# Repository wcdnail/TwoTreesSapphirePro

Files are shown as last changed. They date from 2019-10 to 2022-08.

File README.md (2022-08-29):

# Marlin для TwoTrees Sapphire Pro
## Версия Марлин - 2.1.x, обновлена 26.08.2022

### Внимание!
 - MarlinSP - теперь подмодуль git
 - MKS Robin Nano - STM32F103VET6
 - Баг №1 - произвольное движение каретки при печати - воспроизводится на модерновой гуйне TFT_LVGL_UI
 - ~Драйвера Z & E заменены на 2208~
 - ~Настроен сенсор автоуровня емкостный~ - в прошивке запрещен
 - Настройки сохраняются в SPI Flash (см. Marlin2/src/HAL/HAL_STM32F1/persistent_store_spi_flash.cpp), спасибо [[@sobieh](https://github.com/sobieh)]
 - С графикой помог Korbinian Heel [[@inib](https://github.com/inib)] https://github.com/inib/Marlin/tree/2.0.X-SapphirePro-3.5TFT https://escope.de/posts/sapphire-pro-marlin/ - это уже в актуальной версии Марлин

### Собирать лучше всего с помощью Visual Studio Code + PlatformIO
[Инструкция по установке Visual Studio Code + PlatformIO](https://docs.platformio.org/en/latest/ide/vscode.html)<br/>

### Прошивка SapphirePro:
* После успешной сборки скопировать файл `MarlinSP\.pio\build\mks_robin_nano\Robin_nano35.bin` на sd карту и переименовать в `Robin_nano.bin`
* Установить sd карту в принтер
* Включить/перезагрузить принтер
* Дождаться обновления

### Графика
[Конвертер графики](http://marlinfw.org/tools/u8glib/converter.html)<br/>
`Marlin2\Marlin\_Bootscreen.h` - `Marlin2\Marlin\Configuration.h:91 #define SHOW_CUSTOM_BOOTSCREEN`<br/>
`Marlin2\Marlin\_Statusscreen.h` - `Marlin2\Marlin\Configuration.h:94 #define CUSTOM_STATUS_SCREEN_IMAGE`<br/>
Так же для модификации смотрите директорию `Pixmaps`<br/>

### Тюнинг PID
Нагреватель: `M303 E0 S200 C8`<br/>
Стол: `M303 E-1 C8 S90`<br/>

### Настройки ПО/слайсеров
  Конфигурация|Значение|Примечание
  ------------|----|------
  Скорость соединения с принтером|250000 бод|
  Размер стола|220х220 мм|Ни каких дополнительных смещений настраивать не надо
  Ретракт|8 мм|В заводских настройках указан 9мм
  Скорость ретракта|35-40 мм/c|

#### Пример настройки Repetier-Host
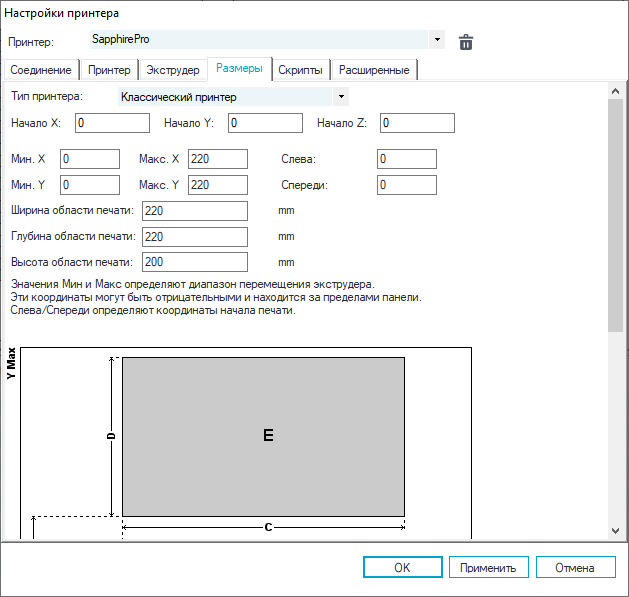
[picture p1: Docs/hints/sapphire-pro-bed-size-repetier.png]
sapphire-pro-bed-size-repetier Размер стола в Repetier-Host


# Железо SapphirePro
 - Матплата - MKS Robin Nano STM32F103VET6
 - Дисплей - MKS TFT35 (3.5" (~9см)) 480*320<br/>

# Стоковые прошивки
`StockFirmwares`

### Скрины
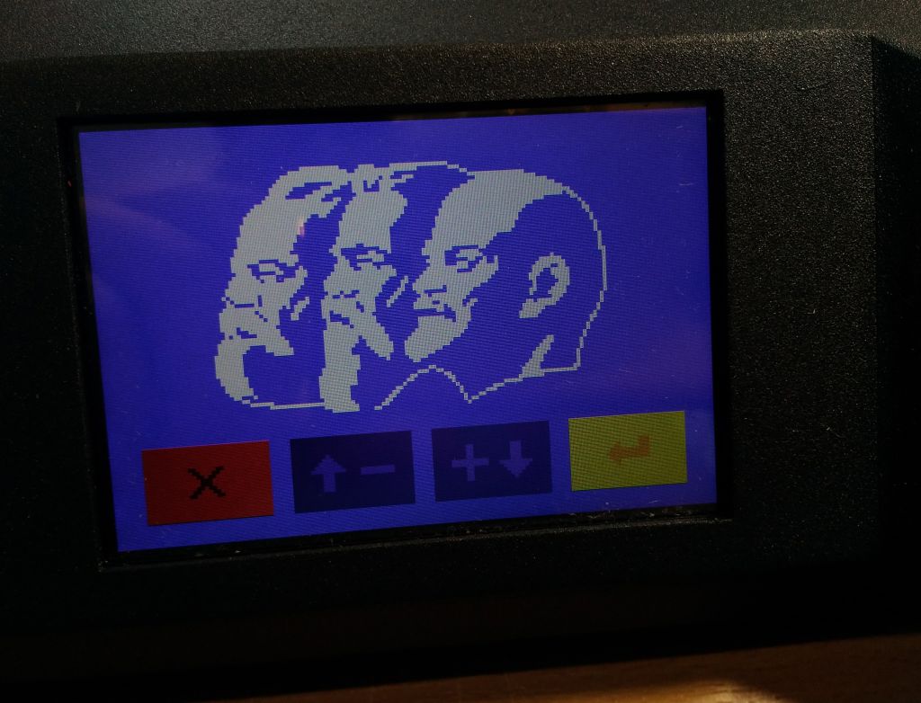
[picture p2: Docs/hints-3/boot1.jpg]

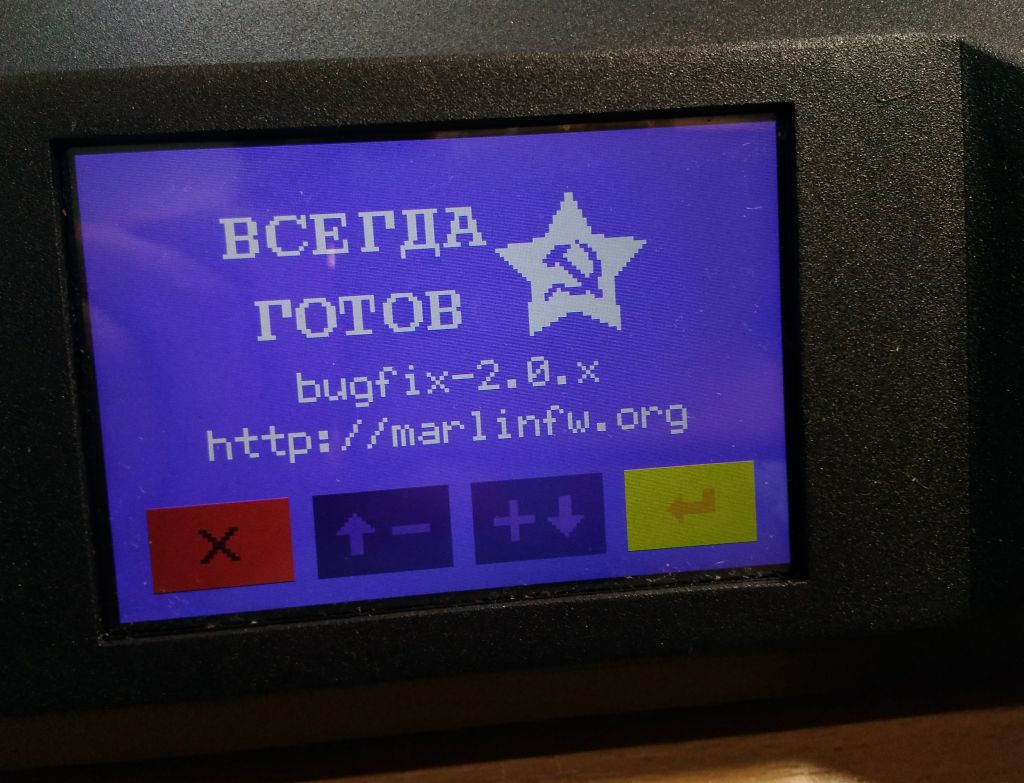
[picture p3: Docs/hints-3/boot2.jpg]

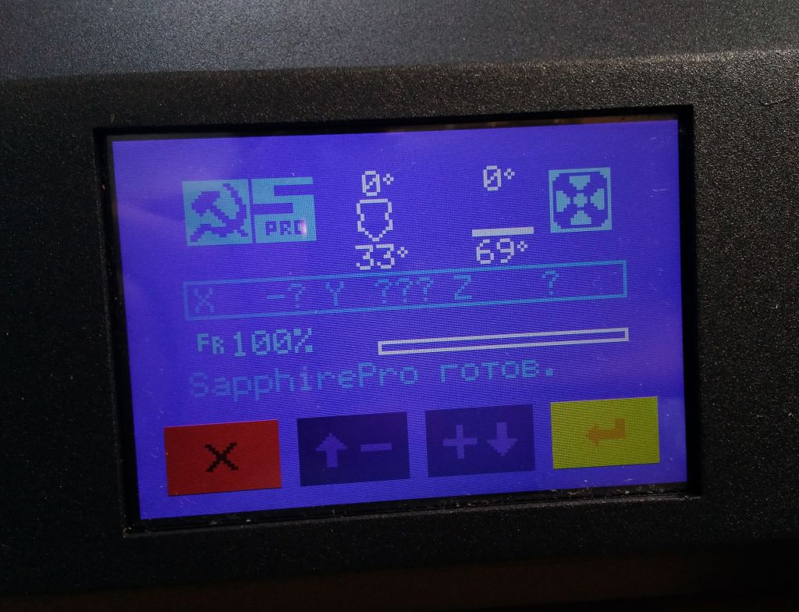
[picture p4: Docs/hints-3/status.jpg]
sapphire-pro-3-marlin-status

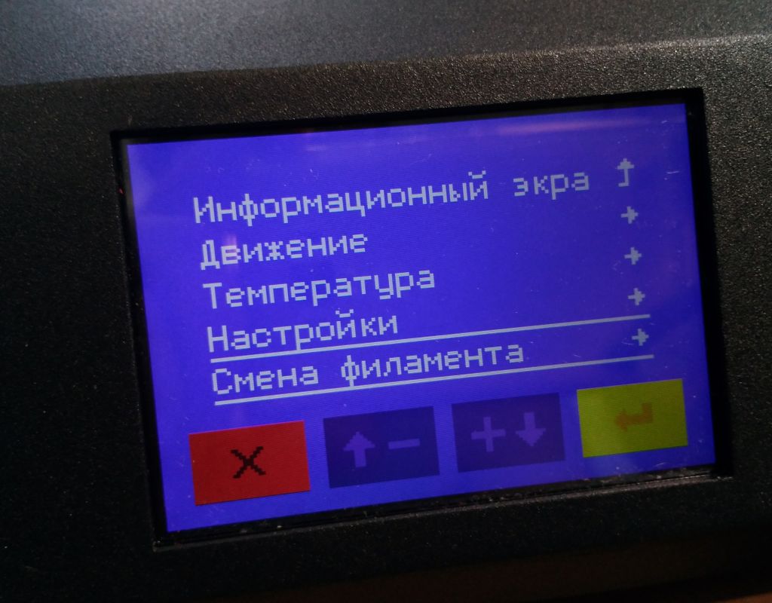
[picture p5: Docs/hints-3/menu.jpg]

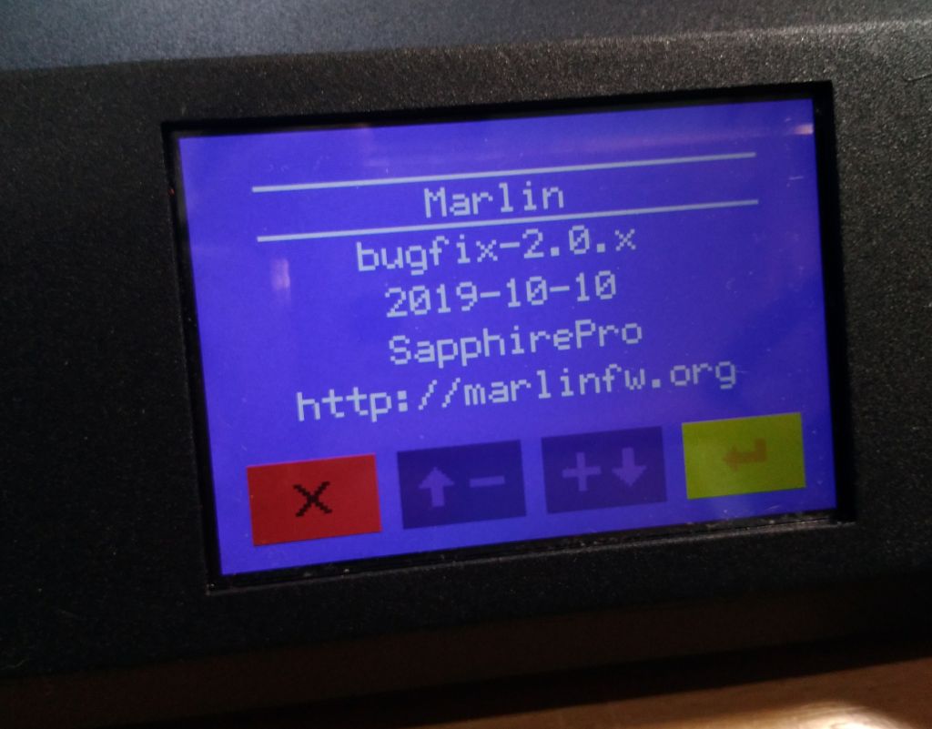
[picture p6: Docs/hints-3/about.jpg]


# Благодарность
## Команде разработчиков марлин
 - Scott Lahteine [[@thinkyhead](https://github.com/thinkyhead)] - USA &nbsp; 
 - Roxanne Neufeld [[@Roxy-3D](https://github.com/Roxy-3D)] - USA
 - Bob Kuhn [[@Bob-the-Kuhn](https://github.com/Bob-the-Kuhn)] - USA
 - Chris Pepper [[@p3p](https://github.com/p3p)] - UK
 - João Brazio [[@jbrazio](https://github.com/jbrazio)] - Portugal
 - Erik van der Zalm [[@ErikZalm](https://github.com/ErikZalm)] - Netherlands &nbsp; 
## С графикой помог
 - Korbinian Heel [[@inib](https://github.com/inib)] https://escope.de/posts/sapphire-pro-marlin/
## EEPROM --> SPI Flash [[@sobieh](https://github.com/sobieh)]
 - https://github.com/inib/Marlin/pull/7

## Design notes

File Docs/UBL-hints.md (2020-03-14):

M190 S75        ; Греем стол
M104 S230       ; Греем хот-енд

M502            ; Сбрасываем текущие настройки
M500            ; Сохраняем текущие настройки
M501            ; Выводим текущие настройки
M851 Z-0.3      ; Установить смещение по Z

G28
G29 P0          ; Zero Mesh Data
G29 T           ; View the Z compensation values.
G29 P1          ; Do automated probing of the bed.
G29 T           ; View the Z compensation values.
G29 S1          ; Save UBL mesh points to EEPROM.
G29 F 30.0      ; Set Fade Height for correction at 30.0 mm.
G29 A           ; Activate the UBL System.
M500            ; Сохраняем текущие настройки. WARNING: UBL will be active at power up, before any `G28`.

G28
G26 B60 H210 F1.75 L0.2 S0.4
 – B температура нагрева стола
 – H температура нагрева экструдера
 – F диаметр филамента
 – L высота слоя 
 - S диаметр сопла

;------------------------------------------
G28
G90                 ; Absolute positioning
G1 Z10 F300         ; Safe Z moving
G1 X110 Y135 F1500  ; Move to centre
M48 P4 V2 E L2      ; Проверить работу датчика уровня
M48 P4 V4 E S1 L3   ; Проверить работу датчика уровня

;------------------------------------------
;--- Setup and initial probing commands ---
;------------------------------------------
M502            ; Reset settings to configuration defaults...
M500            ; ...and Save to EEPROM. Use this on a new install.
M501            ; Read back in the saved EEPROM.  

G28             ; Home XYZ.
G29 P1          ; Do automated probing of the bed.
G29 P2 B T      ; Manual probing of locations USUALLY NOT NEEDED!!!!
G29 P3 T        ; Repeat until all mesh points are filled in.

G29 T           ; View the Z compensation values.
G29 S1          ; Save UBL mesh points to EEPROM.
G29 F 10.0      ; Set Fade Height for correction at 10.0 mm.
G29 A           ; Activate the UBL System.
M500            ; Save current setup. WARNING: UBL will be active at power up, before any `G28`.

;---------------------------------------------
;--- Fine Tuning of the mesh happens below ---
;---------------------------------------------
                
G29 P4 T        ; Move nozzle to 'bad' areas and fine tune the values if needed
                ; Repeat G26 and G29 P4 T  commands as needed.

G29 S1          ; Save UBL mesh values to EEPROM.
M500            ; Resave UBL's state information.

;----------------------------------------------------
;--- Use 3-point probe to transform a stored mesh ---
;----------------------------------------------------
G29 L1          ; Load the mesh stored in slot 1 (from G29 S1)
G29 J           ; No size specified on the J option tells G29 to probe the specified 3 points
                ; and tilt the mesh according to what it finds.

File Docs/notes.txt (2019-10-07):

-- M503 Заводские -------------------------------------------------------------------------------------------------------------------------------------------------------------------------------------------------------------------

08:37:15.982 : echo:  G21    ; Units in mm
08:37:15.985 : echo:Filament settings: Disabled
08:37:15.987 : echo:  M200 D3.00
08:37:15.990 : echo:  M200 T1 D3.00
08:37:15.990 : echo:  M200 D0
08:37:15.993 : echo:Steps per unit:
08:37:15.996 : echo:  M92 X80.30 Y80.30 Z1600.00
08:37:15.999 : echo:  M92 T0 E412.00
08:37:15.999 : M92 T1 E90.00
08:37:16.001 : echo:Maximum feedrates (units/s):
08:37:16.004 : echo:  M203 X200.00 Y200.00 Z4.00
08:37:16.007 : echo:  M203 T0 E70.00
08:37:16.007 : M203 T1 E70.00
08:37:16.012 : echo:Maximum Acceleration (units/s2):
08:37:16.013 : echo:  M201 X1000 Y1000 Z100
08:37:16.015 : echo:  M201 T0 E1000
08:37:16.018 : M201 T1 E1000
08:37:16.024 : echo:Acceleration (units/s2): P<print_accel> R<retract_accel> T<travel_accel>
08:37:16.026 : echo:  M204 P4000.00 R1000.00 T4000.00
08:37:16.038 : echo:Advanced: S<min_feedrate> T<min_travel_feedrate> B<min_segment_time_us> X<max_xy_jerk> Z<max_z_jerk> E<max_e_jerk>
08:37:16.043 : echo:  M205 S0.00 T0.00 B20000 X20.00 Y20.00 Z0.40 E5.00
08:37:16.043 : echo:Home offset:
08:37:16.046 : echo:  M206 X0.00 Y0.00 Z0.00
08:37:16.049 : echo:Hotend offsets:
08:37:16.051 : echo:  M218 T1 X20.00 Y5.00
08:37:16.051 : echo:  M420 S0
08:37:16.054 : echo:Endstop adjustment:
08:37:16.057 : echo:  M666 Z0.00
08:37:16.057 : echo:PID settings:
08:37:16.060 : echo:  M301 P8.41 I0.41 D43.21
08:37:16.063 : echo:Z-Probe Offset (mm):
08:37:16.064 : echo:  M851 Z0.00

**  https://github.com/majurca/MKS-TFT28-NEW-PICTURES
**  https://github.com/jmz52/MKS-Robin-Bootloader
    https://github.com/robotsrulz/MKS-TFT

    https://github.com/makerbase-mks/MKS-TFT/issues/159#issuecomment-405029654
    https://github.com/bigtreetech

   -g: PROGRAM: [====      ]  38.0% (used 199380 bytes from 524288 bytes)
no -g: PROGRAM: [====      ]  38.0% (used 199380 bytes from 524288 bytes)

08:29:41.698 : FIRMWARE_NAME:Marlin 1.0.0 (Github) SOURCE_CODE_URL:https://github.com/MarlinFirmware/Marlin PROTOCOL_VERSION:1.0 MACHINE_TYPE:3D Printer EXTRUDER_COUNT:2 UUID:cede2a2f-41a2-4748-9b12-c55c62f367ff
08:29:41.698 : Cap:SERIAL_XON_XOFF:0
08:29:41.699 : Cap:EEPROM:1
08:29:41.699 : Cap:VOLUMETRIC:1
08:29:41.702 : Cap:AUTOREPORT_TEMP:1
08:29:41.704 : Cap:PROGRESS:0
08:29:41.705 : Cap:PRINT_JOB:1
08:29:41.707 : Cap:AUTOLEVEL:1
08:29:41.707 : Cap:Z_PROBE:1
08:29:41.710 : Cap:LEVELING_DATA:1
08:29:41.710 : Cap:BUILD_PERCENT:0
08:29:41.713 : Cap:SOFTWARE_POWER:0
08:29:41.713 : Cap:TOGGLE_LIGHTS:0
08:29:41.716 : Cap:CASE_LIGHT_BRIGHTNESS:0
08:29:41.719 : Cap:EMERGENCY_PARSER:0
08:29:41.735 : X:0.00 Y:220.00 Z:22.80 E:-1.00 Count X:17666 B:-17666 Z:36480
08:29:41.740 : echo:DEBUG:????????%iy %id %ih %im %is,??????%iy %id %ih %im %is
08:29:41.740 : echo:Active Extruder: 0
08:29:41.747 : Error:checksum mismatch, Last Line: 9
08:29:41.747 : Resend: 10
08:29:41.760 : Begin file list
08:29:41.762 : System Volume Information.DIR
08:29:41.767 : Kabelklammer_2 +1.gcode
08:29:41.776 : End file list
08:29:41.791 : echo:DEBUG:????????%iy %id %ih %im %is,??????%iy %id %ih %im %is
08:29:41.791 : echo:Active Extruder: 0

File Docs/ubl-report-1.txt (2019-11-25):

12:26:11.273 : Bed Topography Report:
12:26:11.283 : ( 20,200)                      (200,200)
12:26:11.294 : 0       1       2       3       4
12:26:11.295 : 4 | +0.141  +0.141  +0.110  +0.089  +0.166
12:26:11.295 : |
12:26:11.296 : 3 | +0.029  +0.056  +0.067  +0.063  +0.052
12:26:11.298 : |
12:26:11.299 : 2 | -0.084  -0.029  +0.024  +0.037  -0.061
12:26:11.299 : |
12:26:11.302 : 1 | -0.078  +0.000 [+0.020] +0.017  -0.026
12:26:11.302 : |
12:26:11.303 : 0 | +0.008  +0.069  +0.151  +0.099  -0.020
12:26:11.315 : 0       1       2       3       4
12:26:11.325 : ( 20, 20)                      (200, 20)

12:50:37.584 : Bed Topography Report:
12:50:37.594 : ( 20,200)                      (200,200)
12:50:37.604 : 0       1       2       3       4
12:50:37.606 : 4 | +0.074  +0.052  +0.266  -0.004  +0.067
12:50:37.606 : |
12:50:37.607 : 3 | +0.007  +0.052  +0.133  -0.008  +0.015
12:50:37.608 : |
12:50:37.610 : 2 | -0.060  +0.055  -0.000  -0.012  -0.036
12:50:37.610 : |
12:50:37.612 : 1 | -0.011  -0.043 [-0.007] -0.012  -0.105
12:50:37.612 : |
12:50:37.614 : 0 | -0.008  +0.026  +0.027  +0.033  -0.031
12:50:37.625 : 0       1       2       3       4
12:50:37.635 : ( 20, 20)                      (200, 20)

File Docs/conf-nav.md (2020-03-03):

### Configuration.h
#### Конфигурация стола
  Наименование                                                      |Строка |Примечание
  ------------------------------------------------------------------|-------|----------
  Размер стола                                                      |   1088|
  Минимумы и максимумы стола                                        |   1094|
  Смещение "домашней" позиции MANUAL_X_HOME_POS MANUAL_Y_HOME_POS   |   1344|
  Z_SAFE_HOMING                                                     |   1357|
#### Конфигурация PID
  Наименование                                                      |Строка |Примечание
  ------------------------------------------------------------------|-------|----------
  PID                                                               |    502|M303 E0 S200 C8
  PIDTEMPBED                                                        |    554|M303 E-1 C8 S90
#### Остальные настройки
  Наименование                                                      |Строка |Примечание
  ------------------------------------------------------------------|-------|----------
  EXTRUDE_MAXLENGTH                                                 |    578|
  Константы драйверов                                               |    685|**Z_DRIVER_TYPE  TMC2208_STANDALONE** **E0_DRIVER_TYPE TMC2208_STANDALONE**
  Шаг и ускорение DEFAULT_AXIS_STEPS_PER_UNIT                       |    743|M302 P1 (disable cold extrusion checking)
  INVERT_ * _DIR                                                    |   1051|**INVERT_Z_DIR true** **INVERT_E0_DIR true**
  Сенсор окончания филамента FILAMENT_RUNOUT_SENSOR                 |   1138|ВЫКЛ
  Калибровка стола AUTO_BED_LEVELING_BILINEAR                       |   1202|ВЫКЛ
  Калибровка стола AUTO_BED_LEVELING_UBL                            |   1203|
  Калибровка стола MESH_BED_LEVELING                                |   1204|ВЫКЛ
  Калибровка стола MESH_BED_LEVELING настройки                      |   1297|ВЫКЛ
  Калибровка стола LCD_BED_LEVELING                                 |   1310|
  Калибровка стола LEVEL_BED_CORNERS                                |   1320|
  EEPROM_SETTINGS                                                   |   1444|Сохраняет в SPI Flash
  Настройка пред-нагрева PREHEAT_*                                  |   1480|PREHEAT_1_* : PET-G 215/75 PREHEAT_2_* : ABS 230/90
  Парковка хот-энда NOZZLE_PARK_FEATURE                             |   1502|
  Язык интерфейса LCD_LANGUAGE                                      |   1623|Русский
  Проверка целостности чтения файлов SD_CHECK_AND_RETRY             |   1683|
  "Пищалка" SPEAKER                                                 |   1755|При включении SPEAKER, **прошивка зависает!**

### Configuration_adv.h
  Наименование                                                      |Строка |Примечание
  ------------------------------------------------------------------|-------|----------
  X Y Z_HOME_BUMP_MM                                                |    522|
  HOME_AFTER_DEACTIVATE                                             |    666|
  M73 прогресс LCD_SET_PROGRESS_MANUALLY                            |    908|
  BABYSTEPPING                                                      |   1322|++
  Linear Advance                                                    |   1369|
  FWRETRACT                                                         |   1627|пока ВЫКЛ
  Расширенная пауза                                                 |   1686|
  FILAMENT_CHANGE_UNLOAD_LENGTH                                     |   1693|

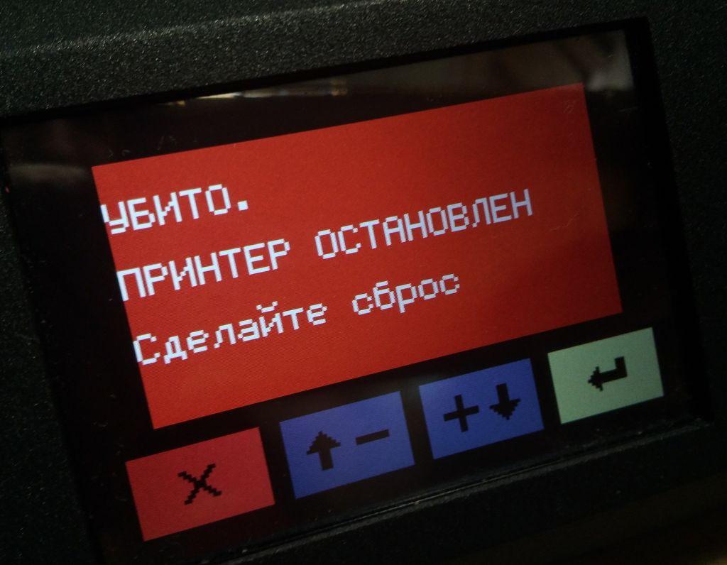
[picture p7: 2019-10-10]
Docs/hints-2/kill-1.jpg

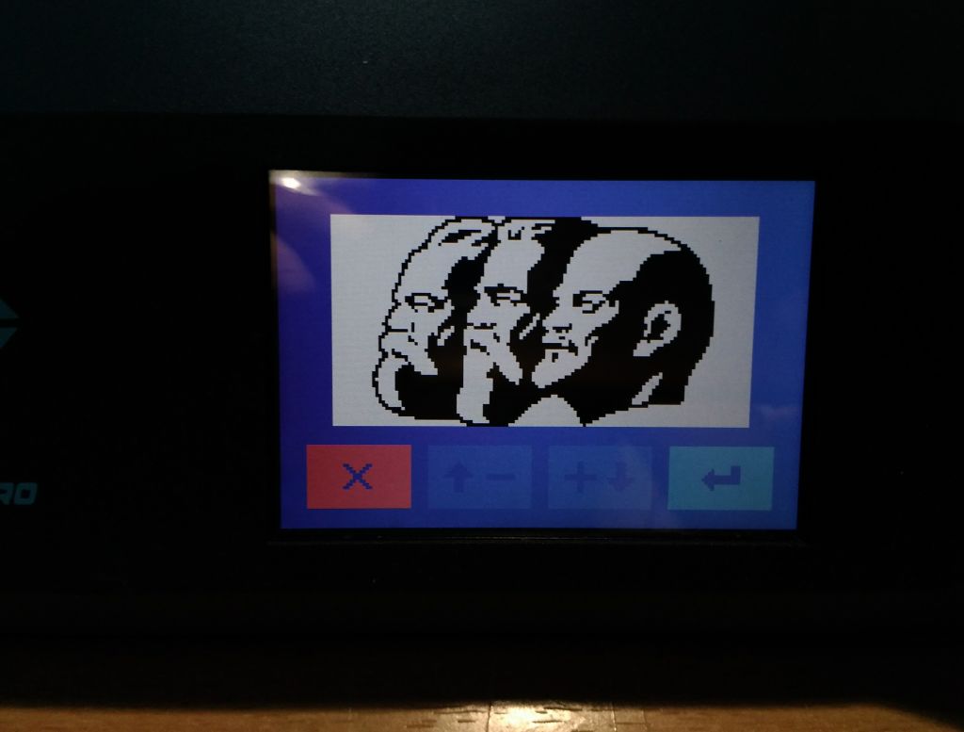
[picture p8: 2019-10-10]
Docs/hints-2/boot-mel.jpg

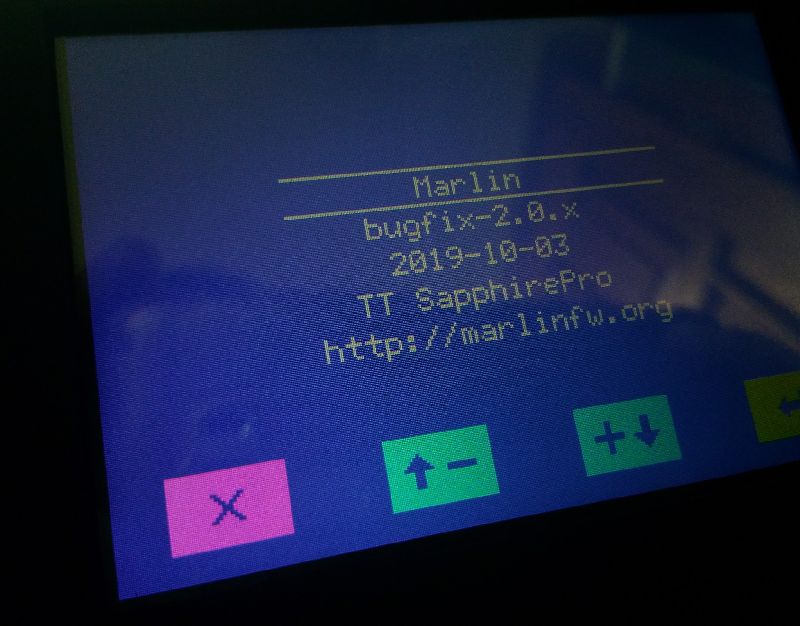
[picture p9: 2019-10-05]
Docs/hints/sapphire-pro-3-marlin-about1.jpg

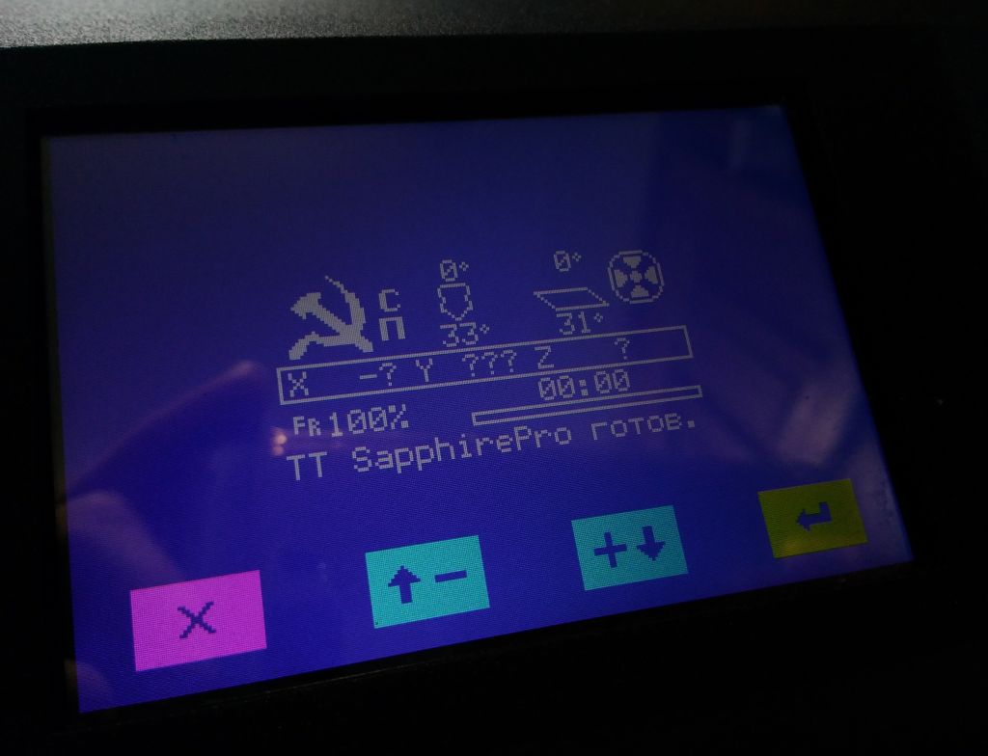
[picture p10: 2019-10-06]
Docs/hints/sapphire-pro-2-marlin-status1.jpg

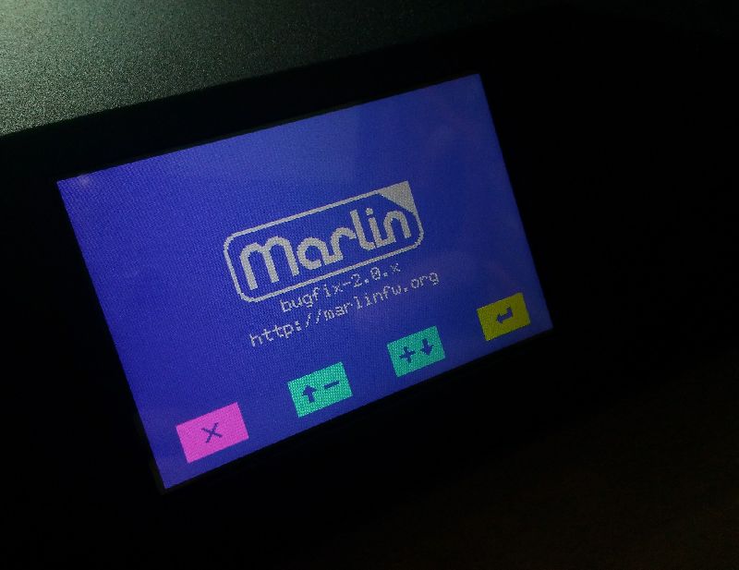
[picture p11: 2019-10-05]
Docs/hints/sapphire-pro-1-marlin-boot2.jpg

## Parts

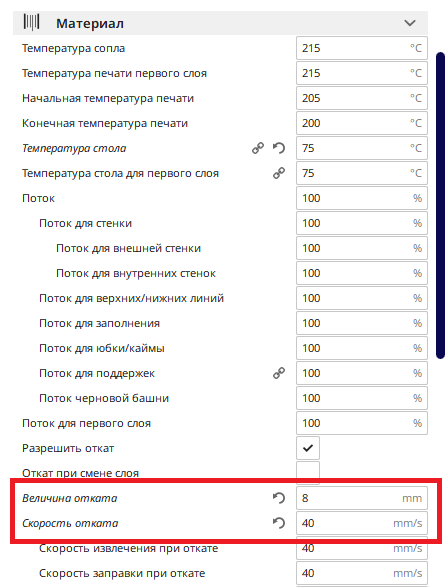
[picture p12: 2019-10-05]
Docs/hints/cura-sapphire-pro-4-material-pet-g.png

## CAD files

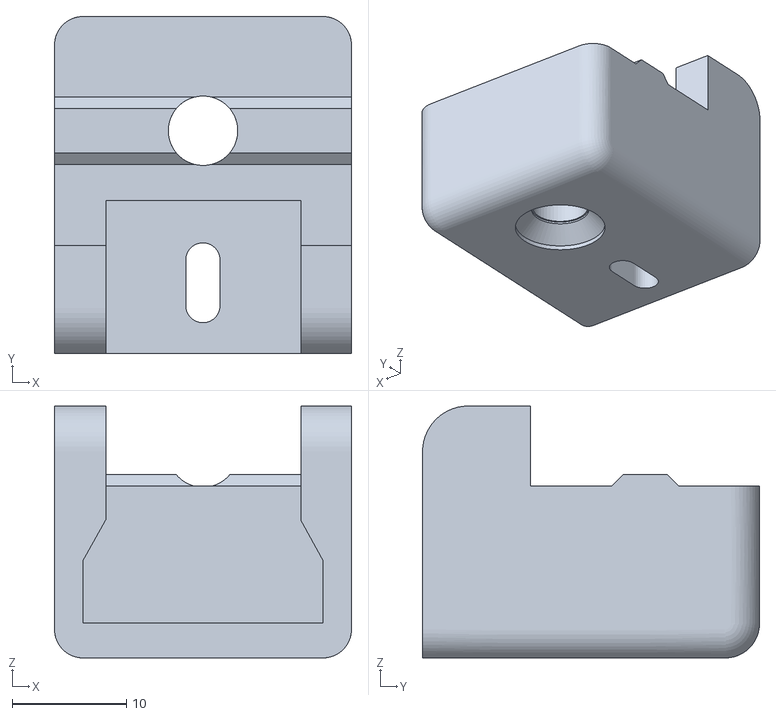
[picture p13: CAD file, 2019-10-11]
Enhancements/07-11-lamp-mount/07-11-2020-Lamp-Mount.stl
26.0 x 29.5 x 22.1

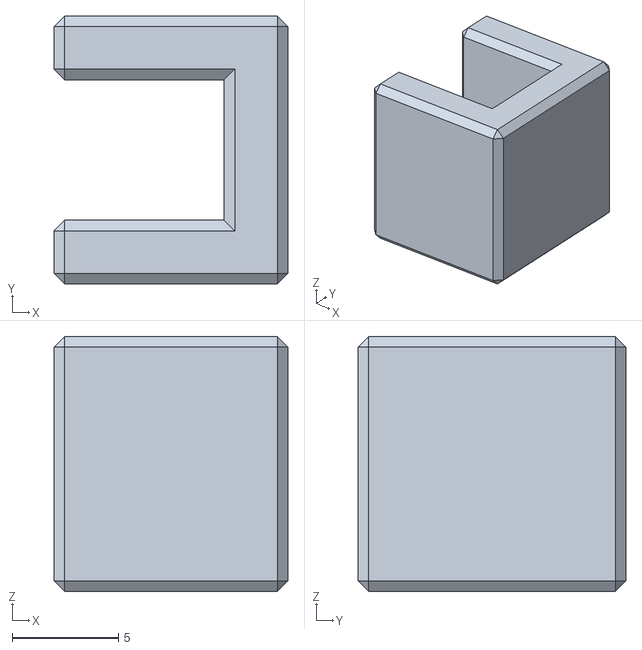
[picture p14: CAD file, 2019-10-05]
Enhancements/bed-clamps-1/bed_clip_3.stl
11.0 x 12.6 x 12.0

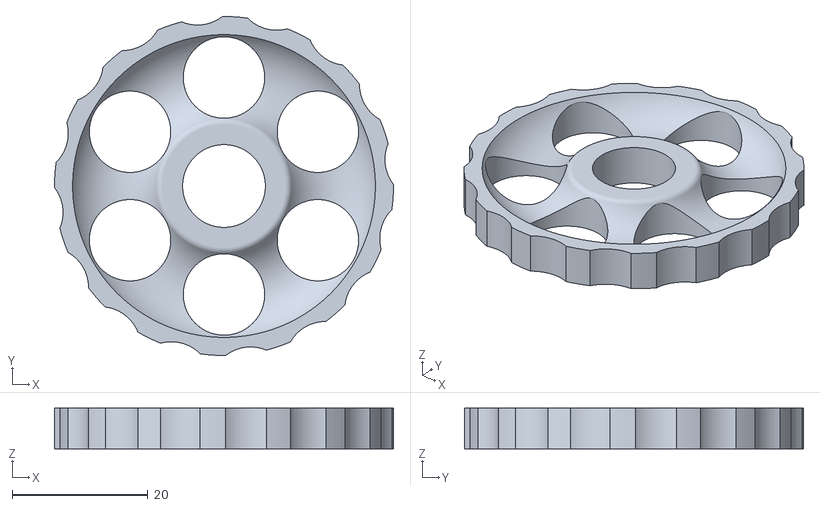
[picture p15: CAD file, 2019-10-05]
Enhancements/bed/bed_adjust_wheel.stl
50.0 x 50.0 x 6.00

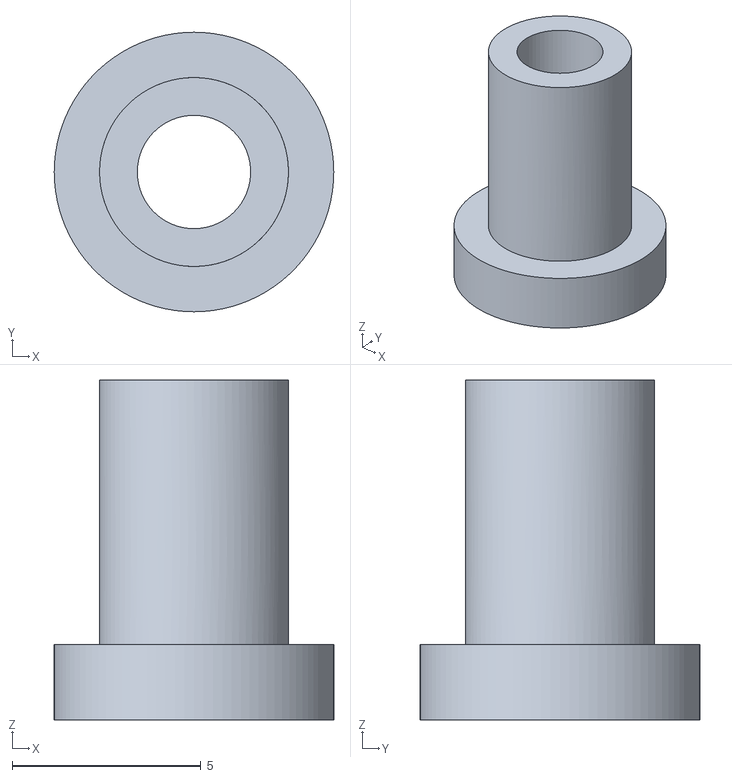
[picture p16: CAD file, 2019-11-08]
Enhancements/bmg/Needle-Bearing-Adapter.stl
7.40 x 7.40 x 9.00

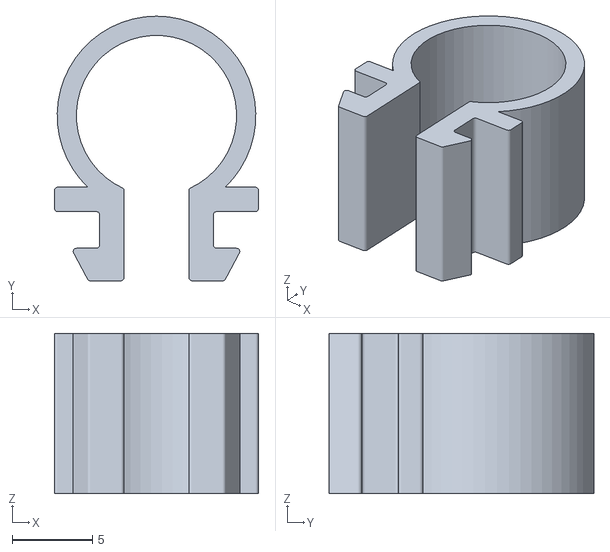
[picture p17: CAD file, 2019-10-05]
Enhancements/cable-mount/10mm_2020_gofr_clip.STL
12.7 x 16.5 x 10.0

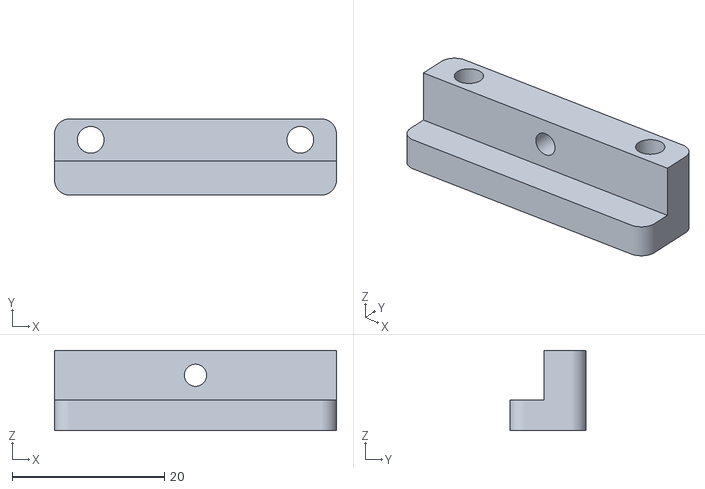
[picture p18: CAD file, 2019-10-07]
Enhancements/extruder-mount/extruder_mount_part2.stl
37.0 x 10.0 x 10.5

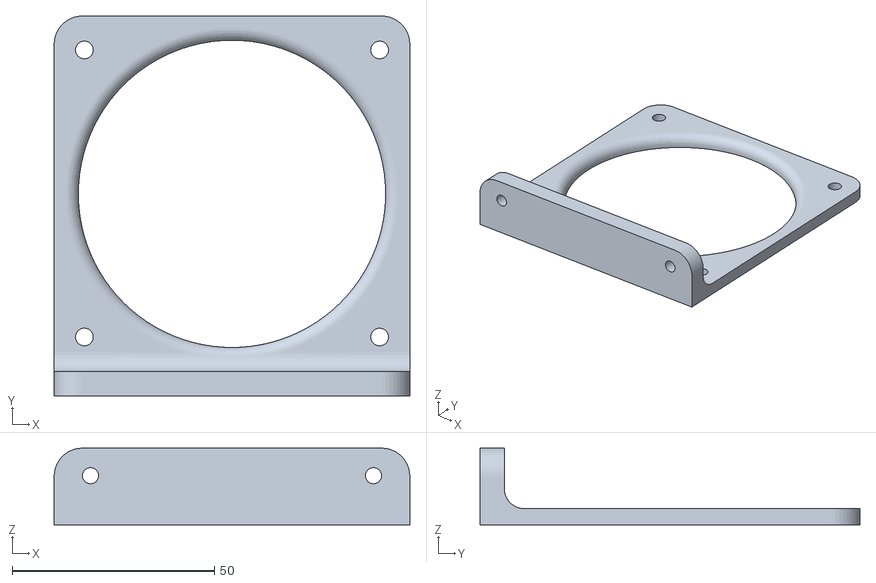
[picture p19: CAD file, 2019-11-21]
Enhancements/fan-mounts/80mm-Fan-Mount.stl
88.0 x 94.0 x 19.0

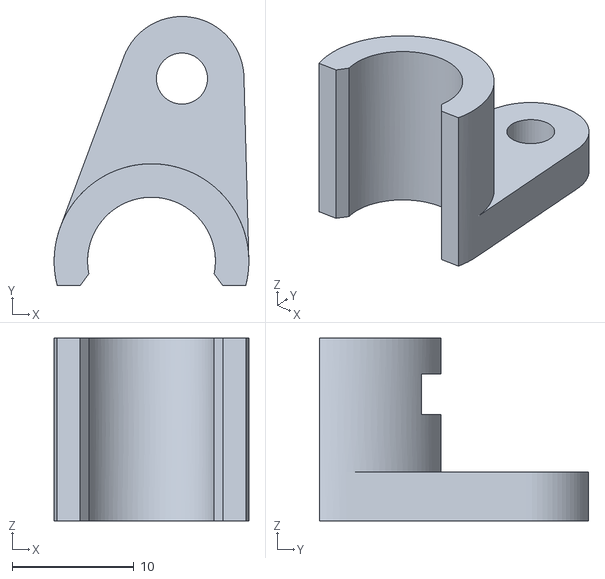
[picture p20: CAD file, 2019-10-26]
Enhancements/gofr-xcar-mount.stl
16.0 x 22.1 x 15.0

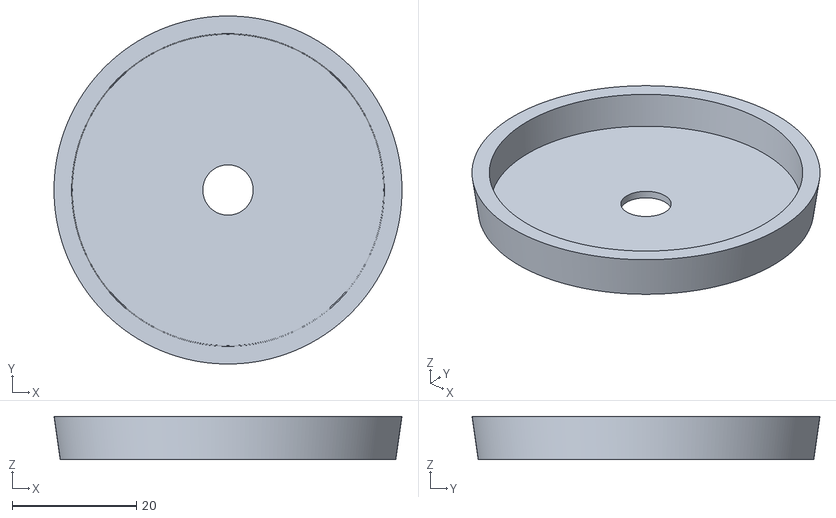
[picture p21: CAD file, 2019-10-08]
Enhancements/spool-holder/spool-holder-50mm-tube-clamp.stl
56.0 x 56.0 x 7.00

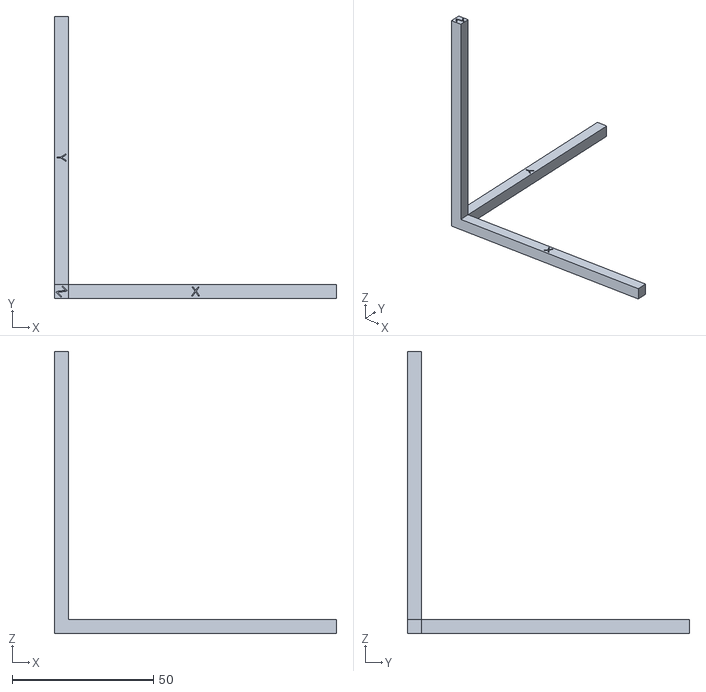
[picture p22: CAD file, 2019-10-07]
Enhancements/xyz-calibration/100x100x100-xyz-calibrate.stl
100.0 x 100.0 x 100.0

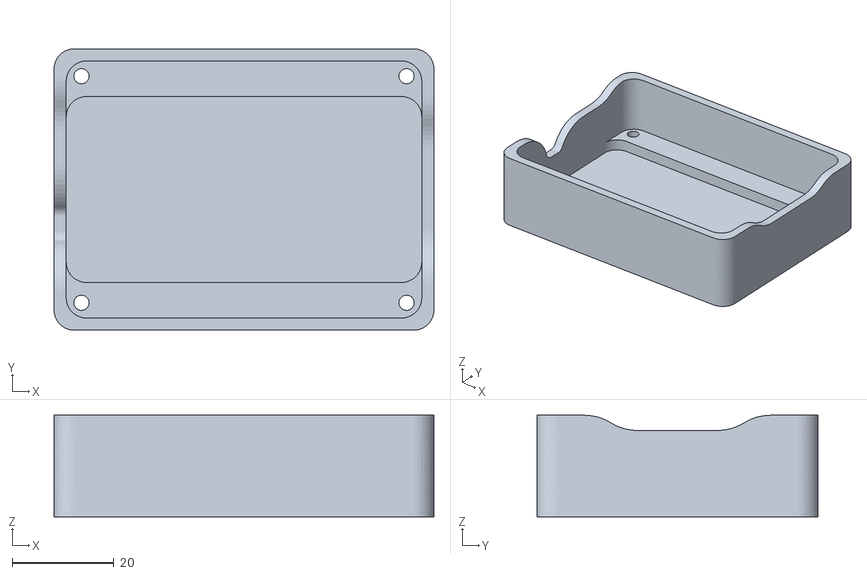
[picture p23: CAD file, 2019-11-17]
Enhancements/z-probe/Z-Probe-Adapter-Case.stl
74.8 x 55.4 x 20.0

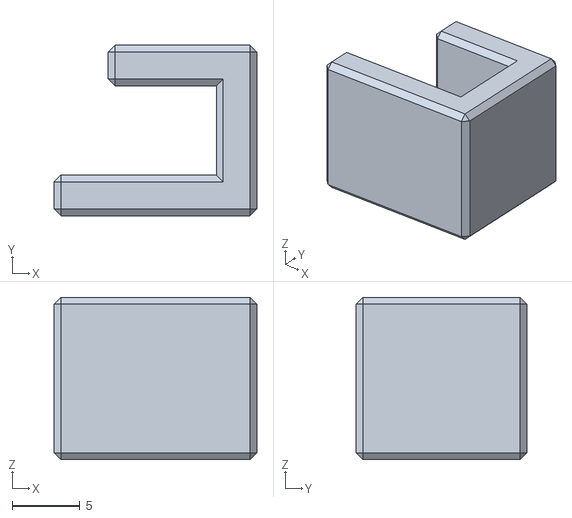
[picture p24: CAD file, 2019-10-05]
Enhancements/bed-clamps-1/bed_clip_1.stl
15.0 x 12.6 x 12.0

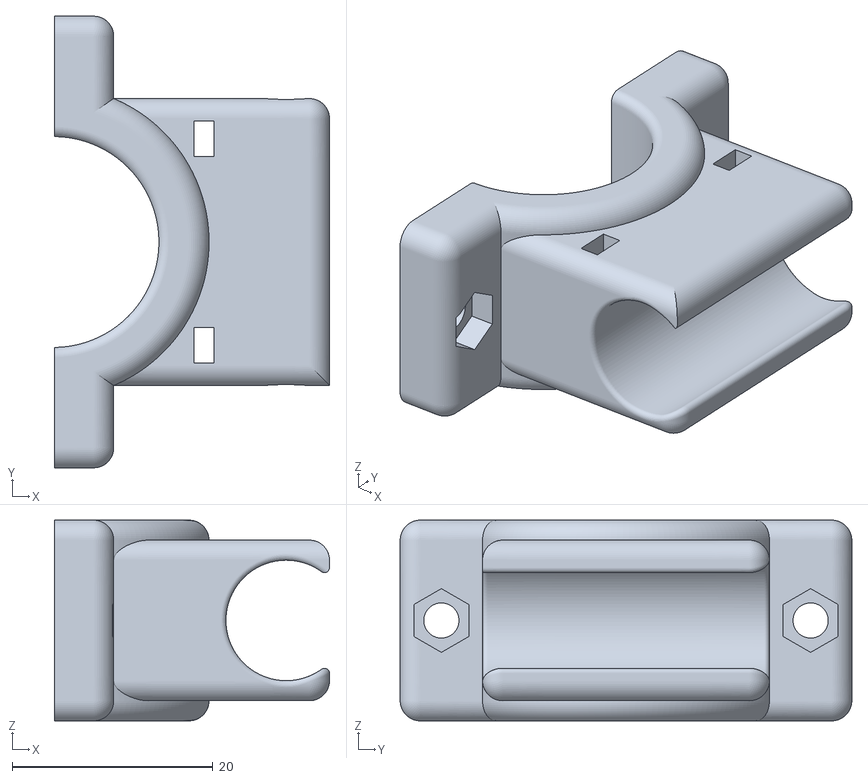
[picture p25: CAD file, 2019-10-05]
Enhancements/bed/Kabelklammer_1.stl
27.4 x 45.0 x 20.0

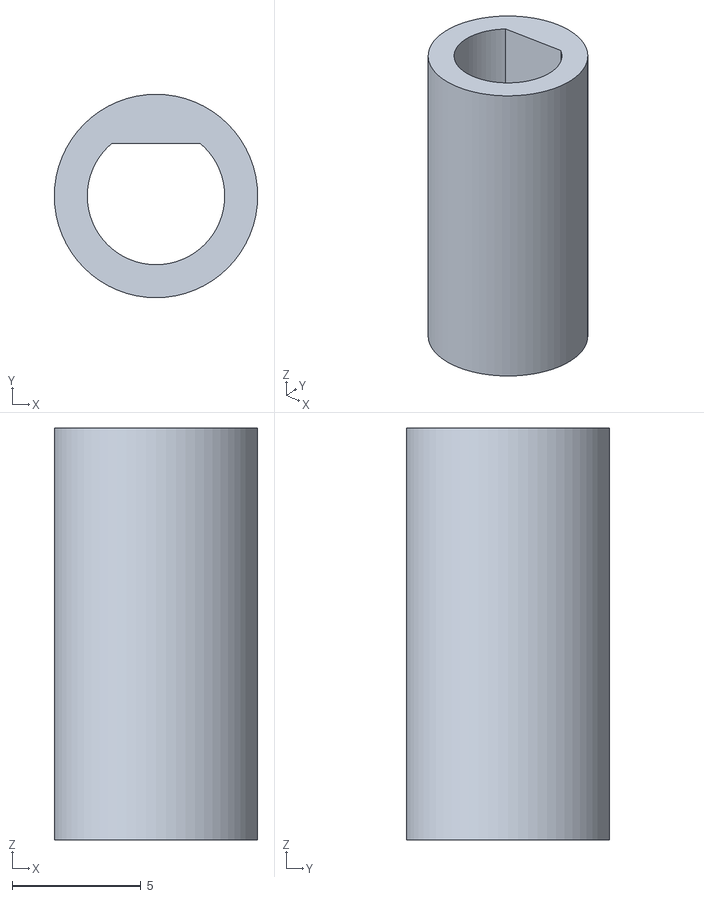
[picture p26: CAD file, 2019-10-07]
Enhancements/extruder-mount/shaft_adapter.stl
7.90 x 7.90 x 16.0

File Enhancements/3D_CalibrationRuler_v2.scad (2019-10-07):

/*
3D Calibration Ruler v2.0

Updated with hole gauge on Y Axis.

Created by Rich Cattell (Thingiverse ID:RichieC)
*/

use <Write.scad>

//X Ruler
translate([0,0,0]) rotate([0,0,0]) Ruler();

//Y Ruler
difference()
	{
	translate([124,22,0]) rotate([0,0,90]) Ruler();
	//Holes
	translate([111,119,-1]) cylinder(r=10/2,h=5,$fn=60);
	translate([111,108,-1]) cylinder(r=9/2,h=5,$fn=60);
	translate([111,98,-1]) cylinder(r=8/2,h=5,$fn=60);
	translate([111,89,-1]) cylinder(r=7/2,h=5,$fn=60);
	translate([111,81,-1]) cylinder(r=6/2,h=5,$fn=60);
	translate([111,74,-1]) cylinder(r=5/2,h=5,$fn=60);
	translate([111,68,-1]) cylinder(r=4/2,h=5,$fn=60);	
	translate([111,63,-1]) cylinder(r=3/2,h=5,$fn=60);	
	translate([111,59,-1]) cylinder(r=2/2,h=5,$fn=60);	
	translate([111,56,-1]) cylinder(r=1/2,h=5,$fn=60);	

}
	//Text for Holes
	translate([105.5,45,1]) rotate([0,0,90]) write("mm -",h=3,t=2);
	translate([105.5,117,1]) rotate([0,0,90]) write("10",h=3,t=2);
	translate([105.5,107,1]) rotate([0,0,90]) write("9",h=3,t=2);
	translate([105.5,97.5,1]) rotate([0,0,90]) write("8",h=3,t=2);
	translate([105.5,88,1]) rotate([0,0,90]) write("7",h=3,t=2);
	translate([105.5,80,1]) rotate([0,0,90]) write("6",h=3,t=2);
	translate([105.5,73,1]) rotate([0,0,90]) write("5",h=3,t=2);
	translate([105.5,67,1]) rotate([0,0,90]) write("4",h=3,t=2);
	translate([105.5,62,1]) rotate([0,0,90]) write("3",h=3,t=2);
	translate([105.5,58,1]) rotate([0,0,90]) write("2",h=3,t=2);
	translate([105.5,55,1]) rotate([0,0,90]) write("1",h=3,t=2);

//Center & XYZ Markings
translate([101,0,0]) cube([23,23,2]);
translate([101,2,1]) write(" X",h =6,t=2);
translate([122,16,1]) rotate([0,0,90]) write("Y",h=6,t=2);
translate([105,26,3]) rotate([90,0,90]) write("Z",h=6,t=2);

//Title
translate([5,13,1]) write("3D Calibration Ruler v2",h=5,t=2);

//Z Tower
translate([102,19,0]) cube([3,22,104]);
difference() 
	{
	translate([80,19,0]) cube([22,3,104]);
	//Z Axis Holes
	translate([91,23,10]) rotate([90,0,0]) cylinder(r=10/2,h=5,$fn=60);
	translate([91,23,23]) rotate([90,0,0]) cylinder(r=9/2,h=5,$fn=60);
	translate([91,23,35]) rotate([90,0,0]) cylinder(r=8/2,h=5,$fn=60);
	translate([91,23,46]) rotate([90,0,0]) cylinder(r=7/2,h=5,$fn=60);
	translate([91,23,56]) rotate([90,0,0]) cylinder(r=6/2,h=5,$fn=60);
	translate([91,23,65]) rotate([90,0,0]) cylinder(r=5/2,h=5,$fn=60);
	translate([91,23,73]) rotate([90,0,0]) cylinder(r=4/2,h=5,$fn=60);
	translate([91,23,80]) rotate([90,0,0]) cylinder(r=3/2,h=5,$fn=60);
	translate([91,23,86]) rotate([90,0,0]) cylinder(r=2/2,h=5,$fn=60);
	translate([91,23,91]) rotate([90,0,0]) cylinder(r=1/2,h=5,$fn=60);
	}

//Text for Z Axis Holes
translate([101,21,6]) rotate([90,270,0]) write("10mm",h=3,t=3);
translate([86,21,20]) rotate([90,270,0]) write("9mm",h=3,t=3);
translate([101,21,32]) rotate([90,270,0]) write("8mm",h=3,t=3);
translate([86,21,43]) rotate([90,270,0]) write("7mm",h=3,t=3);
translate([101,21,53]) rotate([90,270,0]) write("6mm",h=3,t=3);
translate([86,21,62]) rotate([90,270,0]) write("5mm",h=3,t=3);
translate([101,21,70]) rotate([90,270,0]) write("4mm",h=3,t=3);
translate([101,21,70]) rotate([90,270,0]) write("4mm",h=3,t=3);
translate([86,21,77]) rotate([90,270,0]) write("3mm",h=3,t=3);
translate([101,21,83]) rotate([90,270,0]) write("2mm",h=3,t=3);
translate([86,21,88]) rotate([90,270,0]) write("1mm",h=3,t=3);

//Z Ruler
translate([104,41,0]) rotate([0,270,180]) Ruler();

module Ruler()
{
	//The Ruler
	cube([104,22,2]);

	//mm marks
	for (x = [0 : 1 : 100])
		{
		translate([x+1,0,2]) cube([0.5,2,0.8]);
		}
	//5mm marks
	for (x = [0 : 5 : 100])
		{
		translate([x+1,0,2]) cube([0.5,3,1]);
		}
	//10mm marks & Numbers
	for (x = [0 : 10 : 100])
		{
		translate([x+1,0,2]) cube([0.5,5,1]);
		translate([x,6,2]) write(str(x/10),h=2,t=1);
		}
}

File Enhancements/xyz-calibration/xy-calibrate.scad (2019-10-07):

sideWidth = 5;
side      = [sideWidth, sideWidth, sideWidth];
XLength   = 100;
YLength   = 100;
ZLength   = 0;
textZOffs = -0.6;
textZSize = 3;
textSize  = sideWidth/1.5;

translate([-XLength/2, -YLength/2, 0]) {
  difference() {
    union() {
      cube(side+[XLength-sideWidth, 0, 0]);
      cube(side+[0, YLength-sideWidth, 0]);
      if (ZLength > sideWidth) {
        cube(side+[0, 0, ZLength-sideWidth]);
      }
    }
    color("Red") {
      translate([XLength/2, sideWidth/2, sideWidth + textZOffs]) linear_extrude(height=textZSize) text("X", size=textSize, halign="center", valign="center");
      translate([sideWidth/2, YLength/2, sideWidth + textZOffs]) rotate([0, 0, -90]) linear_extrude(height=textZSize) text("Y", size=textSize, halign="center", valign="center");
      if (ZLength > sideWidth) {
        translate([sideWidth/2, sideWidth/2, ZLength + textZOffs]) rotate([0, 0, -45]) linear_extrude(height=textZSize) text("Z", size=textSize, halign="center", valign="center");
      }
    }
  }
}

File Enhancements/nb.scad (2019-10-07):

module SKIPtestNutsAndBolts()
{
	$fn = 360;
	translate([0,15])nutHole(3, proj=2);
	boltHole(3, length= 30, proj=2);
}

MM = "mm";
INCH = "inch";

METRIC_NUT_AC_WIDTHS =
[
	-1, //0 index is not used but reduces computation
	-1,
	-1,
	6.40,//m3
	8.10,//m4
	9.20,//m5
	11.50,//m6
	-1,
	15.00,//m8
	-1,
	19.60,//m10
	-1,
	22.10,//m12
	-1,
	-1,
	-1,
	27.70,//m16
	-1,
	-1,
	-1,
	34.60,//m20
	-1,
	-1,
	-1,
	41.60,//m24
	-1,
	-1,
	-1,
	-1,
	-1,
	53.1,//m30
	-1,
	-1,
	-1,
	-1,
	-1,
	63.5//m36
];

METRIC_NUT_THICKNESS =
[
	-1, //0 index is not used but reduces computation
	-1,
	-1,
	2.40,//m3
	3.20,//m4
	4.00,//m5
	5.00,//m6
	-1,
	6.50,//m8
	-1,
	8.00,//m10
	-1,
	10.00,//m12
	-1,
	-1,
	-1,
	13.00,//m16
	-1,
	-1,
	-1,
	16.00//m20
	-1,
	-1,
	-1,
	19.00,//m24
	-1,
	-1,
	-1,
	-1,
	-1,
	24.00,//m30
	-1,
	-1,
	-1,
	-1,
	-1,
	29.00//m36
];

COURSE_METRIC_BOLT_MAJOR_THREAD_DIAMETERS =
[
	-1, //0 index is not used but reduces computation
	-1,
	-1,
	2.98,//m3
	3.978,//m4
	4.976,//m5
	5.974,//m6
	-1,
	7.972,//m8
	-1,
	9.968,//m10
	-1,
	11.966,//m12
	-1,
	-1,
	-1,
	15.962,//m16
	-1,
	-1,
	-1,
	19.958,//m20
	-1,
	-1,
	-1,
	23.952,//m24
	-1,
	-1,
	-1,
	-1,
	-1,
	29.947,//m30
	-1,
	-1,
	-1,
	-1,
	-1,
	35.940//m36
];

module nutHole(size, units=MM, tolerance = +0.0001, proj = -1)
{
	//takes a metric screw/nut size and looksup nut dimensions
	radius = METRIC_NUT_AC_WIDTHS[size]/2+tolerance;
	height = METRIC_NUT_THICKNESS[size]+tolerance;
	if (proj == -1)
	{
		cylinder(r= radius, h=height, $fn = 6, center=[0,0]);
	}
	if (proj == 1)
	{
		circle(r= radius, $fn = 6);
	}
	if (proj == 2)
	{
		translate([-radius/2, 0])
			square([radius*2, height]);
	}
}

module boltHole(size, units=MM, length, tolerance = +0.0001, proj = -1)
{
	radius = COURSE_METRIC_BOLT_MAJOR_THREAD_DIAMETERS[size]/2+tolerance;
//TODO: proper screw cap values
	capHeight = METRIC_NUT_THICKNESS[size]+tolerance; //METRIC_BOLT_CAP_HEIGHTS[size]+tolerance;
	capRadius = METRIC_NUT_AC_WIDTHS[size]/2+tolerance; //METRIC_BOLT_CAP_RADIUS[size]+tolerance;

	if (proj == -1)
	{
	translate([0, 0, -capHeight])
		cylinder(r= capRadius, h=capHeight);
	cylinder(r = radius, h = length);
	}
	if (proj == 1)
	{
		circle(r = radius);
	}
	if (proj == 2)
	{
		translate([-capRadius/2, -capHeight])
			square([capRadius*2, capHeight]);
		square([radius*2, length]);
	}
}

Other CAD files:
Enhancements/Letters.dxf
Enhancements/spool-holder/spool-holder-50mm-tube.stl
Enhancements/xyz-calibration/100x100-xy-calibrate.stl
Enhancements/z-probe/18-Probe-Mount.stl
Enhancements/bed/bed-glass-clamps.scad
Enhancements/07-11-lamp-mount/07-11-2020-Lamp-Mount.f3d
Enhancements/3D_CalibrationRuler_v2.stl
Enhancements/Write.scad
Enhancements/bed-clamps-1/bed_clip_1_3mm_glass.stl
Enhancements/bed-clamps-1/bed_clip_2.stl
Enhancements/bed-clamps-1/bed_clip_4.stl
Enhancements/bed-clamps-1/bed_clip_4_3mm_glass.stl
Enhancements/bed/Kabelklammer_2.stl
Enhancements/bed/bed-glass-clamps.stl
Enhancements/extruder-mount/X_endstop_mount.stl
Enhancements/extruder-mount/extruder_mount.stl
Enhancements/extruder-mount/stepper_mount.stl
Enhancements/spool-holder/spool-holder-50mm-tube.scad

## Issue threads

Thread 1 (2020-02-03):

English version

novio8, 2020-02-03:
Hi,
is there an English version ?
thanx
Anzo

wcdnail, 2020-02-03:
Hi. Yes.
Change #define LCD_LANGUAGE ru to en
Configuration.h, line 1648

novio8, 2020-02-03:
OK, thank you.
Do you experience any problems with your Sapphire Pro, usin your version ?

wcdnail, 2020-02-03:
No, but now I not so often use my printer

Closed 2020-02-03.

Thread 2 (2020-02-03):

Compile Error

novio8, 2020-02-03:
I downloaded your files and I get the following Error.
I use Visual Studio Code  and Platformio

*** [.pio/build/mks_robin_nano/src/src/HAL/HAL_STM32F1/dogm/u8g_com_stm32duino_fsmc.cpp.o] Error 1

thanx

wcdnail, 2020-02-03:
Probably U8glib error. You need another version of it.

wcdnail, 2020-02-03:
Try this out, eng version
[Robin_nano.zip](https://github.com/wcdnail/TwoTreesSapphirePro/files/4148262/Robin_nano.zip)

wcdnail, 2020-02-03:
I use U8glib-HAL 0.4.1

novio8, 2020-02-03:
I don't have TMC driver for Z and E, I have stock configuration.
I downloaded your package of Marlin and I'm getting the following error
*** [.pio/build/mks_robin_nano/src/src/HAL/HAL_STM32F1/dogm/u8g_com_stm32duino_fsmc.cpp.o] Error 1

wcdnail, 2020-02-04:
To short error description. Do you try install U8glib-HAL 0.4.1?

wcdnail, 2020-02-04:
[U8glib-HAL_ID1932.zip](https://github.com/wcdnail/TwoTreesSapphirePro/files/4151674/U8glib-HAL_ID1932.zip)
Copy it to %USERPROFILE%\.platformio\lib\

wcdnail, 2020-02-04:
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

novio8, 2020-02-04:
I followed your instructions and Compile finished without an Error
I will flash Sapphire later Today and let you know how it went
thanx

novio8, 2020-02-05:
I'v run a test print and it seems Sapphire runs as expected

wcdnail, 2020-02-05:
Glad to hear that. Welcome

Closed 2020-02-05.

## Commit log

2019-10-05 Переезд СапфирПро в отдельный реп
    [Configuration.h, Configuration_adv.h]
2019-10-05 + NOZZLE_PARK_FEATURE - BOOT_MARLIN_LOGO_SMALL + ADVANCED_PAUSE_FEATURE
    [Configuration.h, Configuration_adv.h]
2019-10-06 Яркое предупреждение в шапке
    [Configuration.h]
2019-10-06 + EXTRUDE_MAXLENGTH 750 ++ FILAMENT_CHANGE_UNLOAD_LENGTH 730 + GRID_MAX_POINTS_X 2 + LEVEL_BED_CORNERS ++ LEVEL_CENTER_TOO + BUTTON_DELAY_EDIT 100
    [Configuration.h, Configuration_adv.h]
2019-10-06 + BUTTON_DELAY_EDIT 64 ++ FILAMENT_CHANGE_FAST_LOAD_FEEDRATE 40 ++ FILAMENT_CHANGE_FAST_LOAD_LENGTH 600 + xy-calibrate.scad
    [100x100-xy-calibrate.stl, Configuration.h, Configuration_adv.h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]
2019-10-06 Increase DEFAULT_AXIS_STEPS_PER_UNIT ++ calibration
    [100x100-xy-calibrate.stl, 100x100x100-xyz-calibrate.stl, Configuration.h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]
2019-10-07 Нормальное масштабирование картинки на 480х320
    [Configuration.h]
2019-10-07 Всегда готов!
    [Configuration.h, Configuration_adv.h]
2019-10-07 + FILAMENT_CHANGE_SLOW_LOAD_LENGTH 75 + FILAMENT_CHANGE_FAST_LOAD_LENGTH 500
    [Configuration_adv.h, nb.scad, spool-holder-50mm-tube-clamp.stl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]
2019-10-07 Обновление исходников Marlin (bugfix-2.0.x) от 07.10.2019
    [Configuration.h, Configuration_adv.h]
2019-10-07 + PID 4 E3D V6 блок + TFT_COLOR_GREEN_THEME + Кронштейн экструдера на верхнюю раму (сингиверс)
    [Configuration.h, X_endstop_mount.stl, extruder_mount.stl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]
2019-10-08 + Color by regions + Update all gfx + Adjust bed leveling corners
    [Configuration.h, Configuration_adv.h, spool-holder-50mm-tube-clamp.stl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]
2019-10-08 + LEVEL_CORNERS_INSET 50
    [Configuration.h]
2019-10-08 Временно отключил цветность статусного экрана
2019-10-09 Рефакторинг цветовой схемы
2019-10-09 + Z_HOMING_HEIGHT == 5 mm + S_CURVE_ACCELERATION + Z step/mm == 1600
    [Configuration.h]
2019-10-09 + ADAPTIVE_STEP_SMOOTHING + STATUS_HEAT_PERCENT + BABYSTEPPING + FILAMENT_CHANGE_UNLOAD_LENGTH & so on
    [Configuration_adv.h]
2019-10-10 -- obsolete files
    [Configuration.h]
2019-10-10 Marlin source update
2019-10-10 - second fan config
2019-10-10 ++ МЭЛ bootscreen
2019-10-11 Переделан крепеж освещения
    [07-11-2020-Lamp-Mount.stl, SapphirePro-Lamp-Mount (M).stl, SapphirePro-Lamp-Mount.stl]
2019-10-11 + F360 модель
    [07-11-2020-Lamp-Mount.f3d]
2019-10-11 Marlin update 10.10.2019
    [Configuration.h, Configuration_adv.h]
2019-10-12 Z & E: TMC2208
    [Configuration.h]
2019-10-12 Marlin update
2019-10-14 dec E DEFAULT_MAX_FEEDRATE down to 60 Marlin update
    [Configuration.h]
2019-10-26 + BAUDRATE 250000 + PID + E STEP PER MM
    [Configuration.h, Configuration_adv.h, gofr-xcar-mount.stl]
2019-10-26 Marlin 2.0.x-bugfix merge
    [Configuration.h, Configuration_adv.h]
2019-10-26 + Z_SAFE_HOMING
    [Configuration.h]
2019-10-26 - Z_SAFE_HOMING
    [Configuration.h]
2019-10-27 ИЗМЕНЕН РАЗМЕР СТОЛА!
    [Configuration.h]
2019-10-29 Подправил размеры стола
    [Configuration.h]
2019-11-08 BMG needle bearing fixup
    [Needle-Bearing-Adapter.stl]
2019-11-17 Bugfix-2.0 update
    [Configuration.h, Configuration_adv.h, Z-Probe-Adapter-Case.stl]
2019-11-17 Capacitive Z Probe Marlin bugfix-2.0 upgrade
    [Configuration.h, Configuration_adv.h]
2019-11-23 Bugfix-2 update
    [Configuration.h, Configuration_adv.h]
2019-11-23 Сохранение настроек в SPI Flash (не на SD карту) Спасибо sobieh https://github.com/inib/Marlin/pull/7
    [Configuration.h, Configuration_adv.h]
2019-11-23 Adjust PIDs
    [Configuration.h]
2019-11-24 UBL ON
    [Configuration.h]
2019-11-25 - Z offset from Configuration.h
    [Configuration.h]
2019-12-06 Мерж Marlin 2.0
    [Configuration.h, Configuration_adv.h]
2019-12-26 Fresh 2.0.x update
    [Configuration.h, Configuration_adv.h]
2020-01-03 Возврат к механическому концевику Z
    [Configuration.h, Configuration_adv.h]
2020-01-05 ++ Extruder steps/mm
    [Configuration.h]
2020-02-02 2.0.3 update
    [Configuration.h, Configuration_adv.h]
2020-03-02 Update Marlin 2.0.4.4. & Sapphire Pro as submodule
    [Configuration.h, Configuration_adv.h]
2022-08-24 Marlin update up to 2.1.x
    Probe was turned off
    UI to default modern
